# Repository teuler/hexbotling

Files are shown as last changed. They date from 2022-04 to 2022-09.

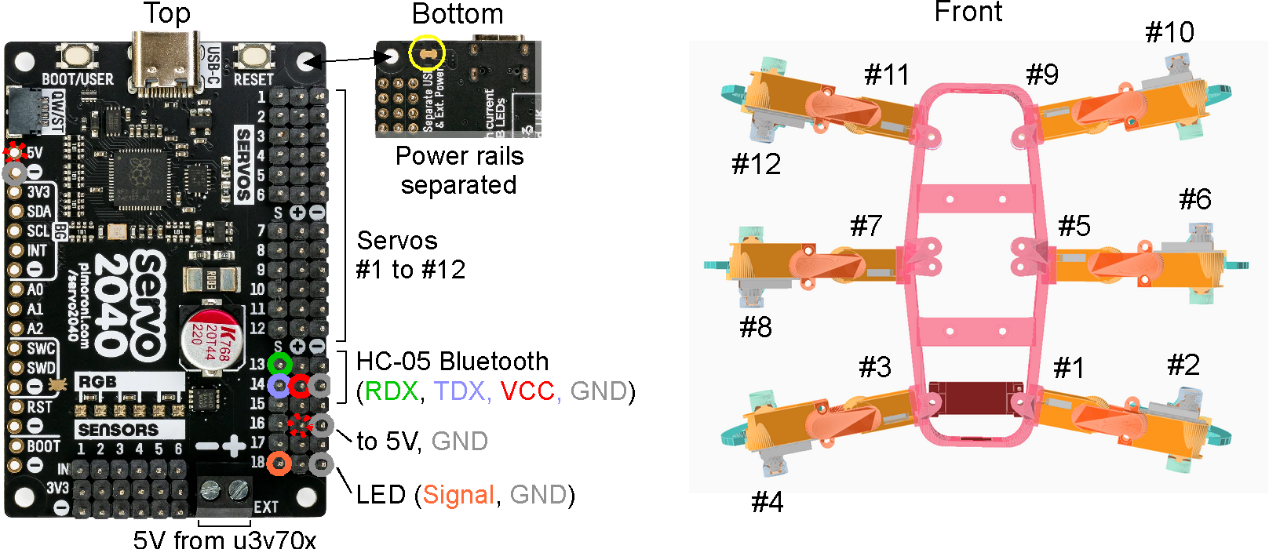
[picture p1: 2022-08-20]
pictures/setup_remote_version_1.png

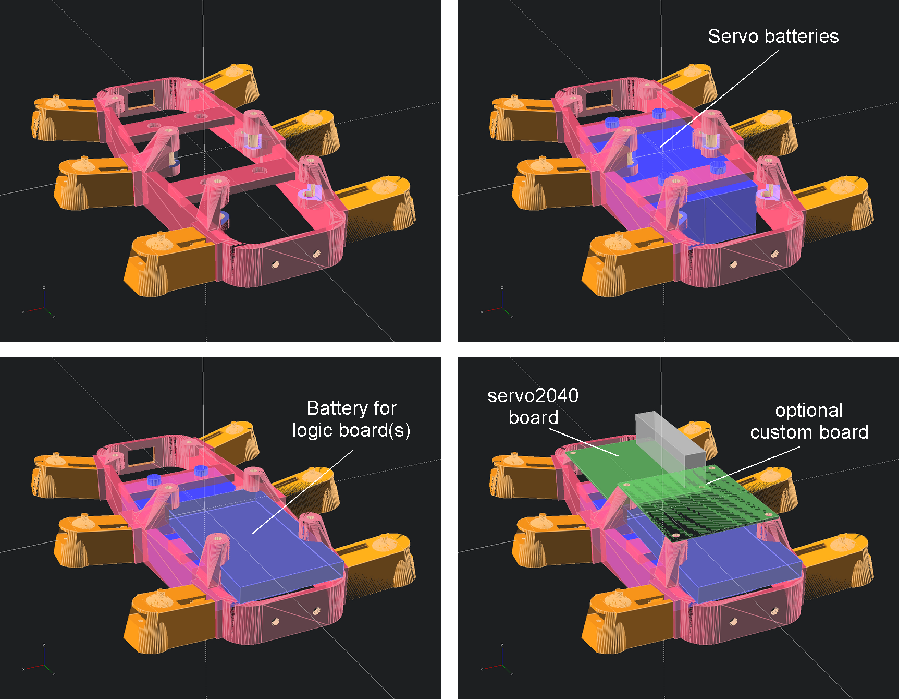
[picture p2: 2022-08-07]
pictures/body_design.png

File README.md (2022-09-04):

# Hexbotling

Hexbotling is a robotic project in progress. The goal is a relatively small and simple, 3D printed walking robot with 6 legs and 2 degrees-of-freedom (2DOF) each. Instead of documenting a finished project, I will show the development. 

Check out the [Wiki](https://github.com/teuler/hexbotling/wiki) for details.

The following videos are available:
* [How it began - Prototyping a leg](https://youtu.be/HZH1UBr0M4s)
* [Preview 1 - First steps](https://youtu.be/tBBJNqaDOq4)

### Release Notes

* 2022-09-03 - First pre-release of the code for the remote controlled test version.
* 2022-08-19 - `scad` code and `.stl` files updated (alternative foot). MicroPython code updated. Wiki pages describing the remote-controlled test version of the robot added.
* 2022-07-10 - `.scad` code updated; holder for servo voltage converter added.
* 2022-06-05 - `.stl` files for legs and body frame added; `.scad` code for these parts added as well.
* 2022-04-19 - Initial release

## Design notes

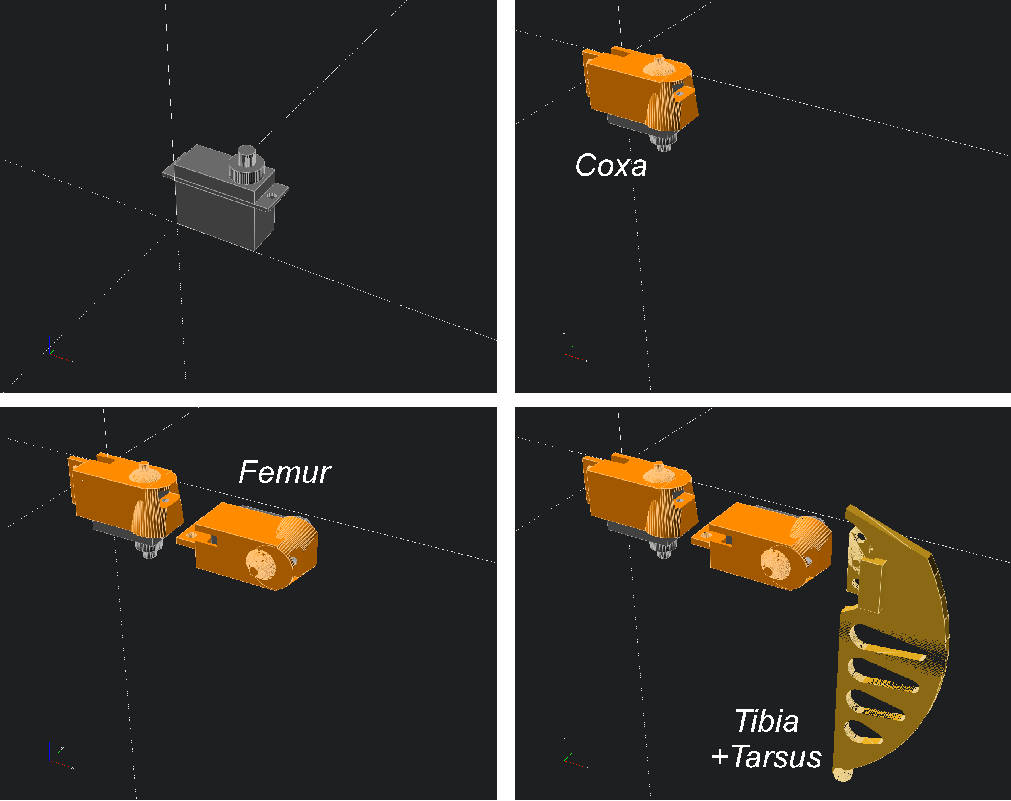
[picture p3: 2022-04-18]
pictures/leg_design.png

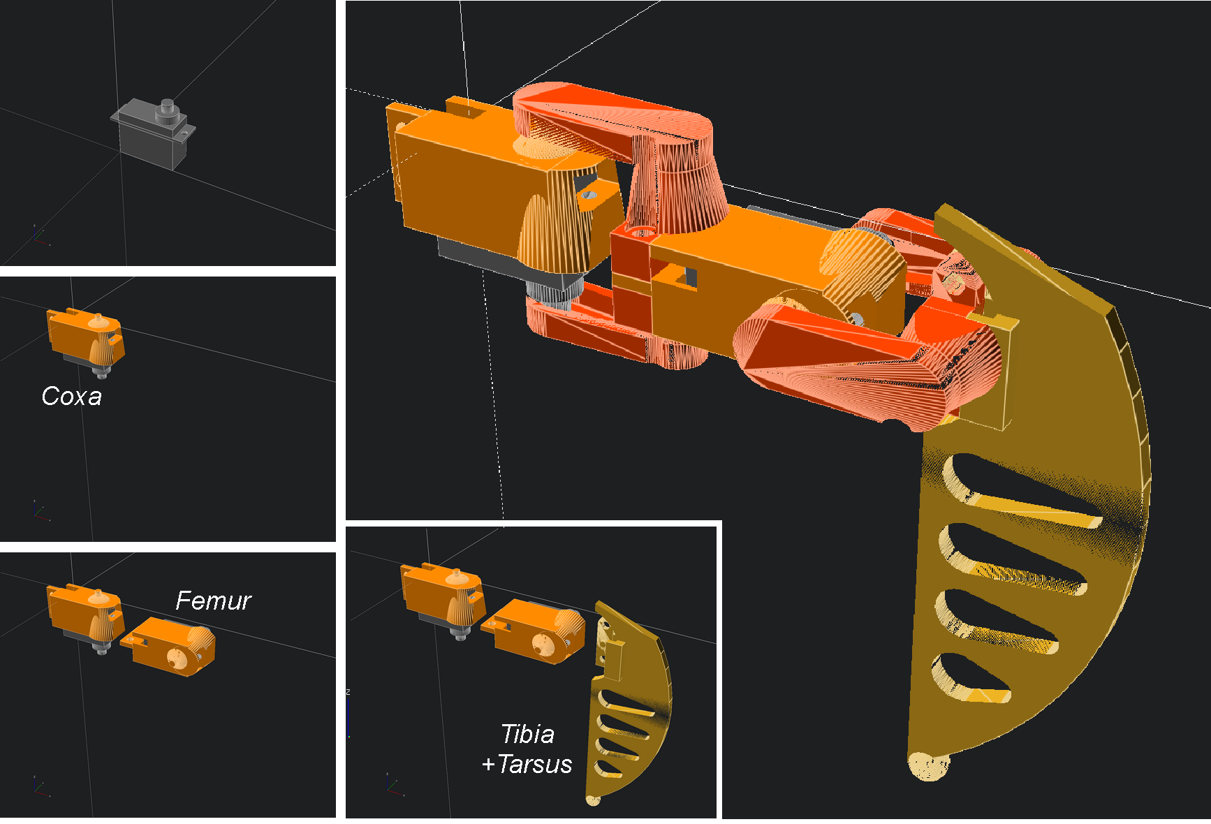
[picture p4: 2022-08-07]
pictures/leg_design_2.png

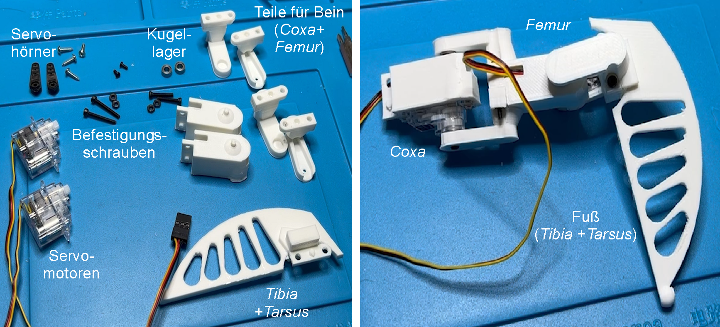
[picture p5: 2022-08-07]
pictures/leg_3_wLabels.png

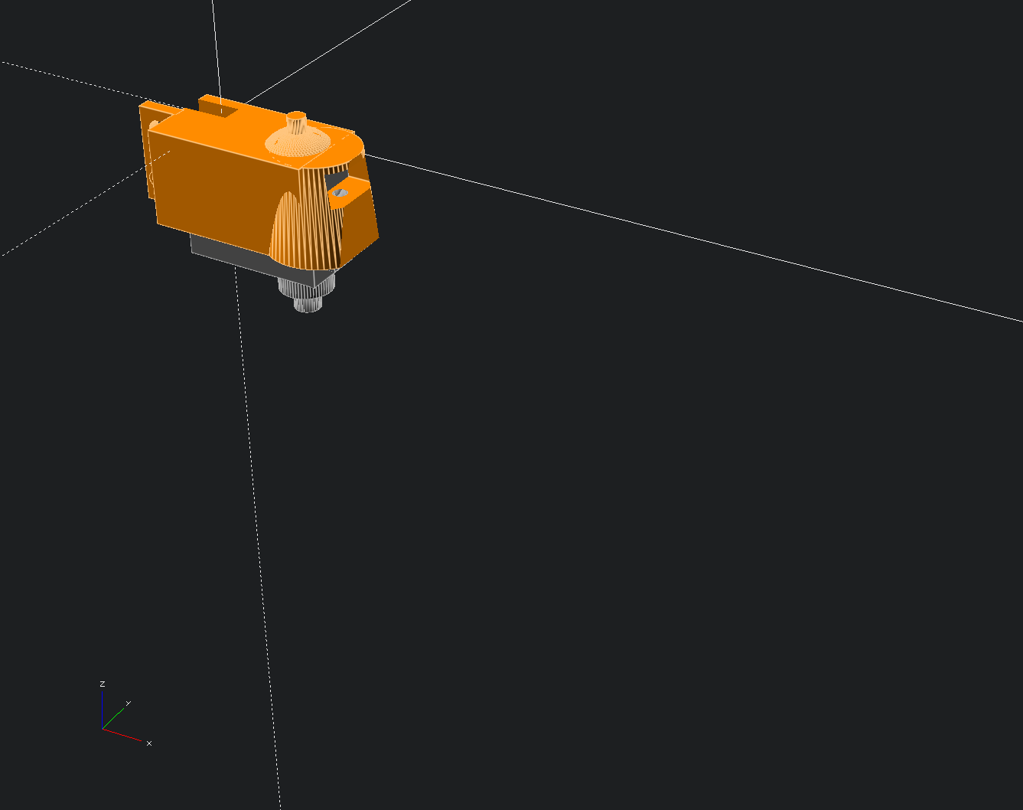
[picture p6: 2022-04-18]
pictures/scad_2.png

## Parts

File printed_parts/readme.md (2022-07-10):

## 3D printed parts

For [OpenSCAD](http://openscad.org/)-code files, see [subfolder](https://github.com/teuler/hexbotling/tree/main/printed_parts/openscad_files).

- `body_frame_v1.stl` - Frame of the robot, to which the legs are attached.
- `converter_holder_v1.stl` - Holder for servo voltage converter.
- `leg_coxa_femur_v1.stl` - Servo holder, which serves as base element for _coxa_ and _femur_. Note that the servo holder for the _coxa_ is integrated into the robot's frame
- `leg_link_bottom_v1.stl` - Bottom half of the clamp that connectes leg parts.
- `leg_link_top_v1.stl` - Top half of the clamp that connectes leg parts.
- `leg_tibia_tarsus_v1a.stl` - _Tibia_ and _tarsus_ in one piece (2DOF), so basically the "foot".
- `stand_v1.stl` - Stand to mount the robot on while calibrating/testing the leg movements.

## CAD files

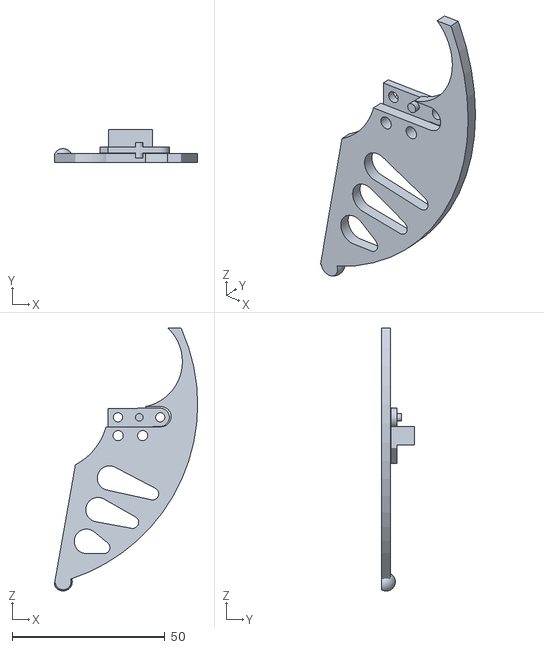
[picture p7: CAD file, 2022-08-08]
printed_parts/leg_tibia_tarsus_v2.stl
46.9 x 10.8 x 86.0

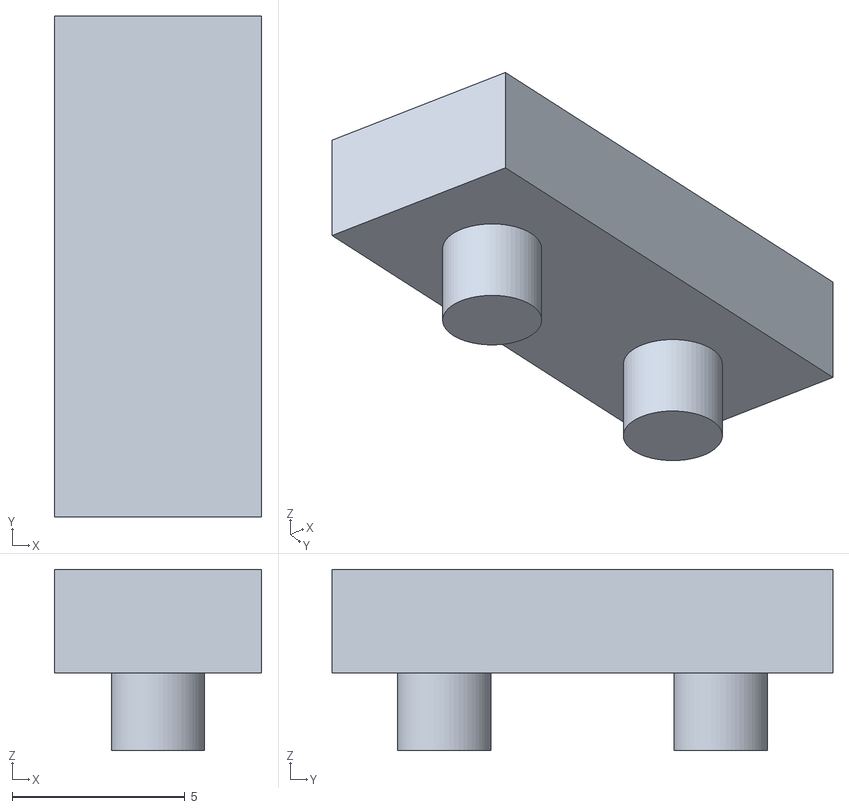
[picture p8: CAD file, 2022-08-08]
printed_parts/leg_tibia_tarsus_v2_adapter_v1.stl
6.00 x 14.5 x 5.25

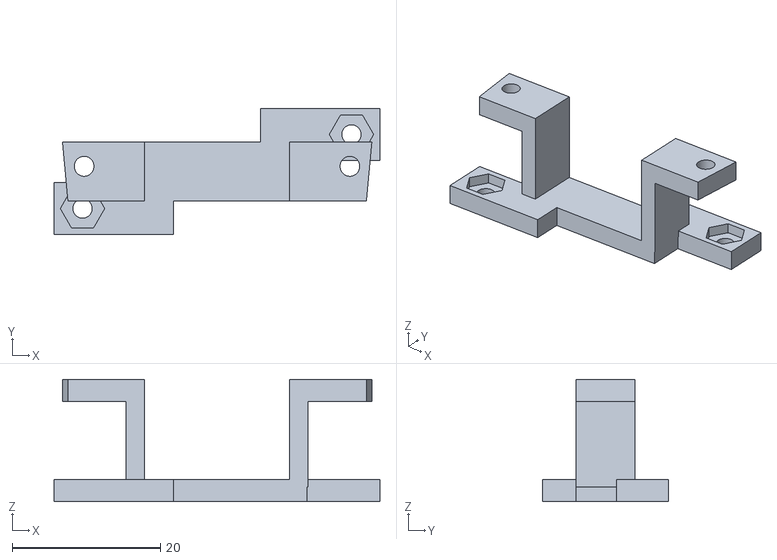
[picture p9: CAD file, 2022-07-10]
printed_parts/converter_holder_v1.stl
44.0 x 17.0 x 16.5

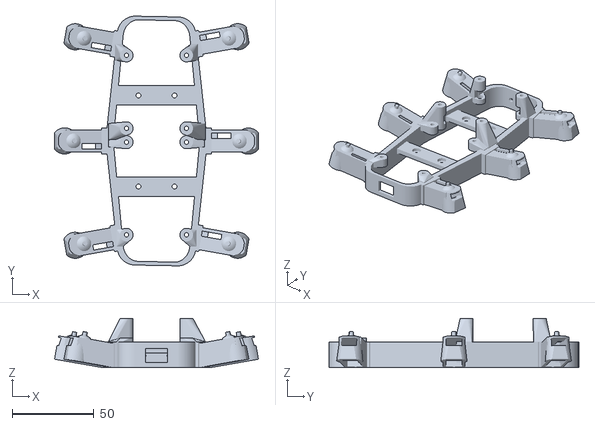
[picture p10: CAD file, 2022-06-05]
printed_parts/body_frame_v1.stl
124.6 x 152.5 x 30.0

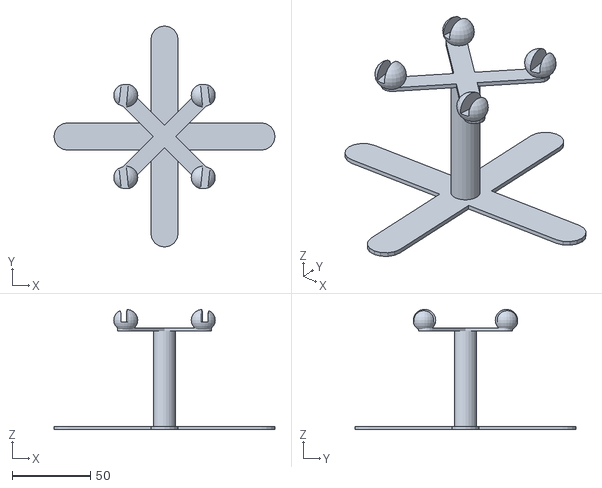
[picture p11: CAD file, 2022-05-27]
printed_parts/stand_v1.stl
141.2 x 141.2 x 76.9

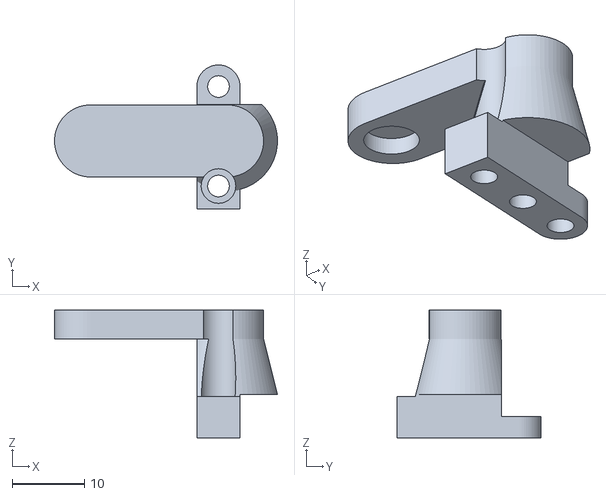
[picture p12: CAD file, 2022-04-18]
printed_parts/leg_link_top_v1.stl
30.9 x 20.0 x 17.8

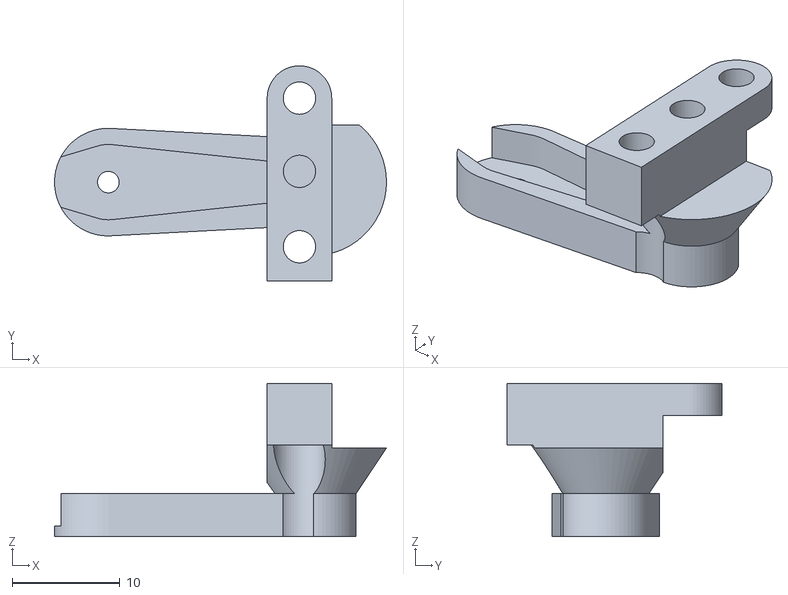
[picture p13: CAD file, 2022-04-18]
printed_parts/leg_link_bottom_v1.stl
30.8 x 20.0 x 14.2

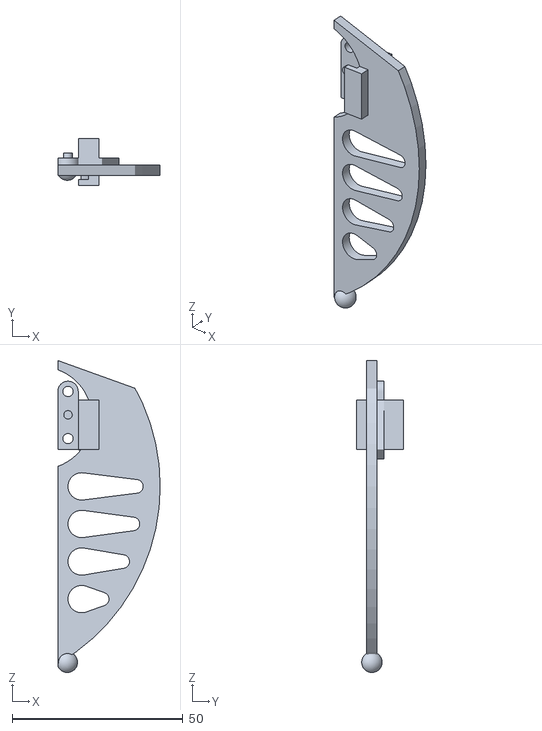
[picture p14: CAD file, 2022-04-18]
printed_parts/leg_tibia_tarsus_v1a.stl
30.0 x 13.8 x 91.4

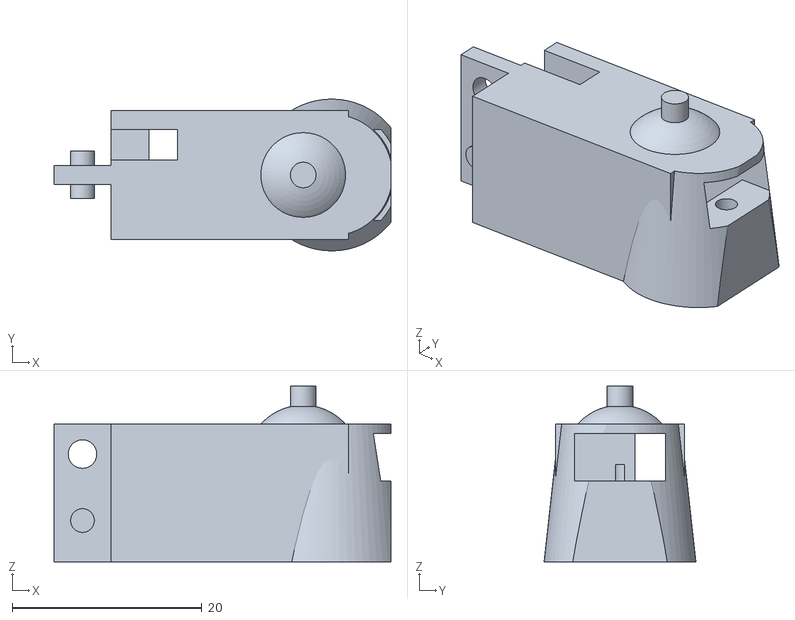
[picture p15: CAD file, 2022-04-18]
printed_parts/leg_coxa_femur_v1.stl
35.5 x 16.0 x 18.5

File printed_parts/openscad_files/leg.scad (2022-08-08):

// --------------------------------------------------------------------------------
// leg.scad (Hexabotling project)
// All modules that define a leg
// (not stand-alone; requires constants defined in the main program)
//
// The MIT License (MIT)
// Copyright (c) 2022 Thomas Euler
//
// --------------------------------------------------------------------------------
module _arm1(px, py, pz, select) {
  // Creates one side ("arm") of a clamp for the legs
  //
  module _front1() {
    translate([srv_axis_x +px -4, -srv_base_dy/2 +0.25, 5])  
    hull() {
      cylinder(h=4, r=5, $fn=_fn);
      translate([15+4, 0,0])  
        cylinder(h=4, r=5, $fn=_fn);
    }  
    translate([srv_axis_x +px +15, -srv_base_dy/2 +0.25, -3])  
      cylinder(h=8, r1=7, r2=5, $fn=_fn);
    translate([px +28, -14, -8.75])  
      cube([6,14.5,5.75]);  
  }
  module _back1() {
    translate([srv_axis_x +px -4, -srv_base_dy/2, 4])  
      cylinder(h=3, r=6.2/2, $fn=_fn);
    translate([srv_axis_x +px +0.75, -14, -21])  
      cube([10, 20, 26]);          
    translate([srv_axis_x +px +10, 0.5, -24])  
      cube([11, 10, 30]);     
    translate([34 +px, -15, -16.5 -0.25])  
      cube([6, 16.5, 13.5 +1 -0.5]);          
    _link_hole(px);  
  }
  if((select == 0) || (select == 1)) {
    difference() {
      union() {
        difference() {
          _front1();
          _back1();
        }
        if(arm_latches) 
          if((select == 0) || (select == 1))
            _arm_latch(px, pz);
      }      
      _link_pin_hole(px);
    }  
  }
}


module _arm2(px, py, pz, select) {
 // Creates the other side ("arm") of a clamp for the legs
 //
  module _front1() {
    translate([srv_axis_x +px -4, -srv_base_dy/2, -25])  
    hull() {
      cylinder(h=4, r=5, $fn=_fn);
      translate([15+4, 0,0])  
        cylinder(h=4, r=4, $fn=_fn);
    }  
    translate([srv_axis_x +px +15, -srv_base_dy/2, -21])  
      cylinder(h=4.5, r1=4, r2=7, $fn=_fn);
    translate([px +28, -14, -16.5])  
      cube([6,14.5,5.75]);          
  }
  module _back1() {
    hull() {
      translate([srv_axis_x +px-4, -srv_base_dy/2, -24])  
        cylinder(h=5, r=7/2, $fn=_fn);
      translate([srv_axis_x +px+15, -srv_base_dy/2, -24])  
        cylinder(h=5, r=3/2, $fn=_fn);
      translate([srv_axis_x +px-5 -6, -srv_base_dy/2, -24])  
        cylinder(h=5, r=3/2, $fn=_fn);
    }  
    translate([srv_axis_x +px -4, -srv_base_dy/2, -27])  
      cylinder(h=10, r=1.0, $fn=_fn);
    translate([srv_axis_x +px -4, -srv_base_dy/2, -27.75])  
      cylinder(h=3, r=6.5/2, $fn=_fn);

    translate([srv_axis_x +px +0.75, -14, -21])  
      cube([10, 20, 26]);          
    translate([srv_axis_x +px +10, 0.5, -24])  
      cube([11, 10, 30]);     
    translate([34 +px, -15, -16.5 -0.25])  
      cube([6, 16.5, 13.5 +1 -0.5]);          
    _link_hole(px);  
  }
  if((select == 0) || (select == 2)) {
    difference() {
      union() {
        difference() {
          _front1();
          _back1();
        }
        if(arm_latches) 
          if((select == 0) || (select == 2))
            _arm_latch(px, pz -5);
      }      
      _link_pin_hole(px);
    }
  }
}

// - - - - - - - - - - - - - - - - - - - - - - - - - - - - - - - - - - - - - - - - 
module _link_hole(px) {
  // Creates the hole for a leg link
  //
  translate([31+px, -4.8 +yoffs_link, -29]) {
    cylinder(h=42, r=r_hole2, $fn=_fn);        
    cylinder(h=10+5, r=r_hole3, $fn=_fn);        
  }
  translate([31+px, -4.8 +yoffs_link, 3-7]) 
    cylinder(h=10+5, r=r_hole3, $fn=_fn);        
}

module _link_pin_hole(px) {
  // Creates the pin for a leg link
  //
  translate([31+px, -9.8 -yoffs_link, -13.25]) 
    cylinder(h=7, r=r_hole2, $fn=_fn);        
}

module _arm_latch(px,pz,dz=3) {
  // Creates the latch that allows combining to leg elements via a clamp
  //
  color("Orange", _alpha1)  
  difference() {
    hull() {
      translate([px +28+3, -4, -8.75 +pz])  
        cylinder(h=dz, r=3, $fn=_fn);      
      translate([px +28+3, 3, -8.75 +pz])    
        cylinder(h=dz, r=3, $fn=_fn);      
    }   
    union() {
      translate([px +28+3, 3, -8.75 +pz+-3])    
        cylinder(h=10, r=1.5, $fn=_fn);      
    }
  }
}

// --------------------------------------------------------------------------------
module Coxa(pxyz=[0,0,0], wServo=false, wSlit=false, noConnect=false) { 
  // Creates the coxa 
  //
  module _body() {
    w = 2;
    translate([-w*2, -w, -w])
      cube([srv_base_dx +w*2, srv_base_dy +w*2, srv_base_dz+ w], center=false);  
    _r = 8;  
    translate([srv_axis_x+2, srv_base_dy/2, -w])  
    cylinder(h=srv_base_dz +2, r1=_r-1.6, r2=_r, $fn=_fn);
    translate([srv_axis_x+srv_axis_x_corr, srv_base_dy/2, -w-4])  
    cylinder(h=3, r=1.35, $fn=_fn);
    translate([srv_axis_x+srv_axis_x_corr, srv_base_dy/2, +2])  
    sphere(r=_r-2, $fn=_fn);
    if(!noConnect)
      translate([-10, srv_base_dy/2 -1, -2])
      cube([6.5, 2, srv_base_dz +w], center=false);  
    if(wSlit) {  
      translate([-10 -1, srv_base_dy/2 -1 -0.5, -2 -1])
      cube([6.5 +1, 2 +1, srv_base_dz +w +2.5], center=false);  
    }
    /*
    translate([srv_axis_x, srv_base_dy/2, -w-4-5])  
      cylinder(h=40, r=1.35, $fn=_fn);
    */  
  }
  module _link_pin() {
    rotate([90,0,0]) 
    translate([-7, srv_base_dz/2 -4.1 -yoffs_link, -7.25]) {
      cylinder(h=5, r=r_hole2-0.25, $fn=_fn);        
      if(wSlit) {
        _dy = (r_hole2-0.25)*2.5;
        translate([-3, -_dy/2, -0.5])
        cube([10, _dy, 6]);
      }  
    }    
  }
  module _link_hole() {
    // Link hole
    rotate([90,0,0]) 
    translate([-7, srv_base_dz/2 +0.9 +yoffs_link, -20]) {
      cylinder(h=30, r=r_hole2, $fn=_fn);          
      if(wSlit) {
        translate([0,0,-4.5])
        cylinder(h=10, r=r_hole2+2, $fn=_fn);        
        translate([0,0,25.2])
        cylinder(h=10, r=r_hole2+2, $fn=_fn);        
      }
    }  
  }  
  
  rotate([180,0,0])
  translate(pxyz) {
    color("DarkOrange",_alpha1)
    difference() {
      union() {
        _body();
        if(wSlit)
          _link_hole();
      }  
      union() {
        Servo([0,0,0.5], wHoles=!wSlit);
        translate([25.5,-4,-3])
          cube([10, 16, srv_base_dz+4]);
        translate([-1, 0, -1])
          cube([28, srv_base_dy, 5]);        
        if(!wSlit) {
          _l = !noConnect? 8: 16;  
          translate([-5, 0, -4])
            cube([_l, srv_base_dy/3, srv_base_dz +2]);      
        }  
        if(!wSlit)
          _link_hole();
      }
    }
    color("DarkOrange", _alpha1)
    _link_pin();    
    if(wServo)
      color("DimGray", _alpha2)
      Servo();
  }
}

// --------------------------------------------------------------------------------
module Femur(pxyz=[0,0,0], wServo=false, select=0) {
  // Creates the femur
  //
  px = pxyz[0] +4;
  py = pxyz[1];
  pz = pxyz[2];
  if((select == 0) || (select == 3)) {
    rotate([90,0,0]) 
      Coxa([px +38, py+5, pz-12], wServo);
  }
  color("OrangeRed", _alpha1)  
  union() {
    _arm1(px, py, pz, select);
    _arm2(px, py, pz, select);
  }  
}

// --------------------------------------------------------------------------------
module Tibia1(pxyz=[0,0,0], select=0) {
  // Creates the tibia
  //
  px = pxyz[0] +8;
  py = pxyz[1];
  pz = pxyz[2];
  _rot = [0, 0, 0];
  _tra = [0, 0, 0];
  
  rotate([90,0,0])
  translate([30 +px, -5+py, 12+pz]) {
    // Arms
    color("OrangeRed", _alpha1)      
    rotate(_rot) 
    translate(_tra)
    union() {
      _arm1(px, py, pz, select);
      _arm2(px, py, pz, select);
    }
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

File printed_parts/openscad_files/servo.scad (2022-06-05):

// --------------------------------------------------------------------------------
// servo.scad (Hexabotling project)
// Modules that define a micro servo
// (stand-alone)
//
// The MIT License (MIT)
// Copyright (c) 2022 Thomas Euler
//
// --------------------------------------------------------------------------------
srv_dspace       = 0.5;
srv_fn           = 60;

// Servo definitions
srv_base_dx      = 20 +srv_dspace*2;
srv_base_dy      = 8.6 +srv_dspace*2;
srv_base_dz      = 12 +srv_dspace;
srv_bar_dx       = 28;
srv_bar_dz       = 1;
srv_top_dz       = 17 -srv_bar_dz -srv_base_dz;
srv_top2_dz      = 20.2 -17;
srv_top3_dz      = 23.5 -20.2;
srv_hole_dist_dx = 17.5 +6;
srv_hole1_x      = (srv_bar_dx -srv_hole_dist_dx)/2;
srv_hole2_x      = srv_hole1_x +srv_base_dx;
srv_axis_x       = srv_hole2_x -6;
srv_axis_x_corr  = -1;

module Servo(pxyz=[0,0,0], axyz=[0,0,0], wHoles=false) {
  // Creates a servo 
  //
  module _Holes() {
    union() {
      translate([-srv_hole1_x+0.25+0.35, srv_base_dy/2, srv_base_dz-4]) 
        cylinder(h=srv_base_dz, r=r_hole4, center=true, $fn=srv_fn);
      translate([srv_hole2_x-0.5-0.35, srv_base_dy/2, srv_base_dz-4]) 
        cylinder(h=srv_base_dz, r=r_hole4, center=true, $fn=srv_fn);
    }
  }
  color("DimGray", _alpha2)
  translate(pxyz) 
  rotate(axyz)
  difference() {
    union() {
      cube([srv_base_dx, srv_base_dy, srv_base_dz], center=false);
      translate([-(srv_bar_dx -srv_base_dx)/2,0, srv_base_dz]) 
        cube([srv_bar_dx, srv_base_dy, srv_bar_dz], center=false);
      translate([0,0, srv_base_dz +srv_bar_dz]) 
        cube([srv_base_dx, srv_base_dy, srv_top_dz], center=false);
      z = srv_base_dz +srv_bar_dz +srv_top_dz;
      translate([srv_axis_x+srv_axis_x_corr, srv_base_dy/2, z]) {
        cylinder(h=srv_top2_dz, r=8/2, center=false, $fn=srv_fn);
        cylinder(h=srv_top3_dz +srv_top2_dz, r=4/2, center=false, $fn=srv_fn);
      }
    }
    _Holes();
  }
  if(wHoles)
    _Holes();
}

// --------------------------------------------------------------------------------

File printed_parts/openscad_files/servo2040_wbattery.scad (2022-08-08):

// --------------------------------------------------------------------------------
// servo2040_wbattery.scad (Hexabotling project)
// Modules that define a servo2040 board and the servo battery pack
// (not stand-alone; requires constants defined in the main program)
//
// The MIT License (MIT)
// Copyright (c) 2022 Thomas Euler
//
// --------------------------------------------------------------------------------
module ServoBattery(n=2) {
  // Creates a servo battery pack
  // (BH-18650-PC_DS Battery holder)
  //
  color("Blue", _alpha2) {
    _zbat = -13+1 -3; 
    dx = [11, -11];
    _h = 8;
    for(i=[0:n-1]) {
      translate([n>1?dx[i]:0, 0, _zbat]) {
        cube([22.9, 77.7, 21.3], center=true); 
        
        translate([0, 55.6/2, 5])
        cylinder(h=_h, r=3/2, $fn=_fn);
        translate([0, 55.6/2, 12])
        cylinder(h=_h, r=6/2, $fn=_fn);

        translate([0, -55.6/2, 5])
        cylinder(h=_h, r=3/2, $fn=_fn);
        translate([0, -55.6/2, 12])
        cylinder(h=_h, r=6/2, $fn=_fn);
        
      }
    }
  }
}    

// --------------------------------------------------------------------------------
function PCB_servo2040_metrics() 
  = [srv2040_dx, srv2040_dy, 
     [[ srv2040_dx/2 -2.7,  srv2040_dy/2 -2.7], 
      [-srv2040_dx/2 +2.7,  srv2040_dy/2 -2.7],
      [ srv2040_dx/2 -2.7, -srv2040_dy/2 +2.7], 
      [-srv2040_dx/2 +2.7, -srv2040_dy/2 +2.7]
     ]];

// - - - - - - - - - - - - - - - - - - - - - - - - - - - - - - - - - - - - - - - -      
module PCB_servo2040(holes_only=false, screw_only=false) {
  // Creates a Pimoroni servo2040 board
  //
  _temp = PCB_servo2040_metrics();
  _dx = _temp[0];
  _dy = _temp[1];
  _xy = _temp[2];
  
  module _pbc() {
    color("ForestGreen", _alpha2)
    cube([_dx, _dy, 1], center=true);
    color("gray", _alpha2)
    translate([0, -_dy/2 +9.5/2, -15/2])
    cube([_dx-2*5, 9.5, 15], center=true);
  }  
  module _holes(_h) {
    for(xy=_xy) {    
      translate([xy[0], xy[1], -2])
      cylinder(h=_h, r=2.7/2, $fn=_fn);
      if(!screw_only) 
        translate([xy[0], xy[1], 15])
        cylinder(h=15, r=2.3, $fn=_fn);
    }  
  }

  rotate([180,0,90]) 
  translate([srv2040_offx, 0, srv2040_offz]) 
  union() {
    if(holes_only) {
      translate([0,0,-10])
      _holes(_h=30);
    }
    else {
      difference() {
        _pbc();
        _holes(_h=10);
      }  
    } 
   } 
}
 
// --------------------------------------------------------------------------------

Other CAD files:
printed_parts/openscad_files/main_v6.scad
printed_parts/openscad_files/main_v4.scad
printed_parts/openscad_files/main_v5.scad
printed_parts/openscad_files/stand.scad

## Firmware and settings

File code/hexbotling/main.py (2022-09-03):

# ----------------------------------------------------------------------------
# main.py
#
# Main program
#
# The MIT License (MIT)
# Copyright (c) 2022 Thomas Euler
# 2022-03-21, v1.0
# ----------------------------------------------------------------------------
import sys
import time
import hxbl_global as glb
import hxbl_config as cfg
import hxbl_comm as com
from hxbl_server import Server
from robotling_lib.misc.helpers import timed_function
from robotling_lib.misc.messenger import MessengerUART
import hxbl_server

# ----------------------------------------------------------------------------
#@timed_function
def handleCmd(msgData):
  """ Handles command in `msgData`, returns ERR_OK or error code
  """
  res = Comm.check(msgData)
  if res is not glb.ERR_OK:
    # Invalid message
    return res, com.MSG_NONE

  # Extract elements
  RSrv.set_msg_LED(True)
  errC = glb.ERR_OK
  msgID = msgData[1]
  params = msgData[2:]
  nParams = len(params)

  # Handle command ...
  if msgID == com.MSG_STOP:
    # Stop robot and wait until in neutral position
    RSrv.stop(wait_for_neutral=True)

  elif msgID == com.MSG_GAIT:
    # Change gait
    RSrv.stop(wait_for_neutral=True)
    RSrv.set_gait_parameters(type=params[0])

  elif msgID == com.MSG_MOVE:
    # Move robot depending on parameters ...
    dir = min(max(params[0], -100), 100) /100
    vel = min(max(params[1]*2, 1), 250) / 100
    rev = params[2] > 0
    lft = params[3]
    RSrv.set_gait_parameters(velocity=vel, lift_deg=lft)
    hxbl_server.g_we._tLastMsg = time.ticks_ms()
    if abs(dir) < 0.1:
      # ... forward
      RSrv.move_forward(reverse=rev)
    else:
      # ... turn
      RSrv.turn(dir)

  elif msgID == com.MSG_POWER_DOWN:
    # Power down
    pass

  elif msgID == com.MSG_PING:
    # Client sent a ping, respond ...
    Comm.send([com.MSG_PING])

  else:
    # Command not recognized
    errC = glb.ERR_UNKNOWN_MSG
    msgID = com.MSG_NONE

  if errC is glb.ERR_OK and msgID is not com.MSG_PING:
    sendStatus(msgID)
  RSrv.set_msg_LED(False)
  return errC, msgID

# - - - - - - - - - - - - - - - - - - - - - - - - - - - - - - - - - - - - - -
#@timed_function
def sendStatus(msgID):
  """ Confirm receipt/execution of command. Includes:
      - message ID (`msgID`)
      - the servo load (in [A]*10)
      - the servo battery voltage (in [V]*10)
  """
  Comm.send(
      [com.MSG_STA, msgID,
      int(RSrv.servo_load_A *10), int(RSrv.servo_battery_V *10)]
    )

# ----------------------------------------------------------------------------
if __name__ == "__main__":

  # Create server instance
  RSrv = Server(core=cfg.HW_CORE, verbose=True)

  # Create a communicator instance and wait for connection to client
  Comm = com.Communicator(MessengerUART(
      chan=cfg.UART_CH, fToLog=glb.toLog,
      tx=cfg.UART_PIN_TX, rx=cfg.UART_PIN_RX, baud=cfg.UART_BAUD
    ))
  RSrv.set_pulse_LED_hue(cfg.HUE_WAITING)
  glb.toLog("Wait for ping from server ...")
  if not Comm.wait_for_client(f_wait_ms=RSrv.sleep_ms):
    glb.toLog("No client connection", errC=glb.ERR_CANNOT_CONNECT)
    RSrv.deinit()
    sys.exit()
  else:
    RSrv.set_pulse_LED_hue(cfg.HUE_NORMAL_BT)
  glb.toLog("Ready.", head=False)

  try:
    is_running = True
    n_rounds = 0
    msgID = com.MSG_NONE

    # Main loop
    glb.toLog("Entering loop ...", head=False)
    try:
      while not RSrv.state == glb.STA_OFF and is_running:
        # Get sensor input and/or commands from client
        # ...

        # Check if message is available
        if Comm.available > 0:
          data = Comm.receive()
          if data is not None and len(data) > 0:
            # If message data ok, handle the message ...
            errC, msgID = handleCmd(data)
            if errC is not glb.ERR_OK:
              glb.toLog("Command not handled", errC=errC)

        # Sleep for a while and, if running only on one core, make sure that
        # the server's hardware is updated
        RSrv.sleep_ms(25)

        # Check if user button is pressed; when debugging, exit also if a
        # maximum number of rounds have been done, as a precaution
        is_running = (
            not RSrv.exit_requested
            and not msgID == com.MSG_POWER_DOWN
          )
        if cfg.DEBUG:
          is_running = is_running and n_rounds < 25_000
        n_rounds += 1

    except KeyboardInterrupt:
      is_running = False
      pass

  finally:
    # Power down and clean up
    glb.toLog("Loop stopped.", head=False)
    RSrv.deinit()

# ----------------------------------------------------------------------------

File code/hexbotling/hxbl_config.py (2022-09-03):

# ----------------------------------------------------------------------------
# hxbl_config.py
#
# Configuration
#
# The MIT License (MIT)
# Copyright (c) 2022 Thomas Euler
# 2022-05-04, v1.0
# 2022-08-07, v1.1 - Improved calculation of the servo calibration values
# ----------------------------------------------------------------------------
import array
from micropython import const
from servo import servo2040 as srv

# pylint: disable=bad-whitespace
# Firmware info
HXBL_VERSION       = 1.1
HXBL_INFO          = "Hexbotling"
DEBUG              = const(1)
CALIBRATE          = []

# Control how hardware is kept updated
HW_CORE            = const(0)   # 1=hardware update runs on second core
APPROX_SPIN_MS     = const(5)   # core==0, approx. duration of hardware update
MIN_UPDATE_MS      = const(20)  # core==0, minimal time between hardware updates
PULSE_STEPS        = const(25)  # Number of steps for Pixel/RGB pulsing

# Global parameters
MAX_CURR_A         = 1.0         # maximum for normalizing sensed current
DT_CURR_UPDATE     = const(50)
MAX_VOLT_V         = 5.5         # maximum for normalizing voltage
BATT_SERVO_THRES_V = 4.6
DT_VOLT_UPDATE     = const(1000)

# LED-related
LEDS_BRIGHTNESS    = 0.4         # maximum LED brighness (0..1)
LEDS_FREQ          = const(60)   # Hz (frequency of LED driver)
ID_LED_CURR        = const(0)    # ID of LED for current load indicator
ID_LED_VOLT        = const(1)    # ID of LED for servo voltage indicator
ID_LED_PULSE       = const(5)    # ID of pulsing LED
HUE_PREPARING      = 0.2
HUE_NORMAL_BT      = 0.6
HUE_WAITING        = 0.0

# Pins for message UART
UART_CH            = const(0)
UART_PIN_TX        = const(12)   # RDX  ->  SERVO13 (GP12, UART0 TX)
UART_PIN_RX        = const(13)   # TDX  ->  SERVO14 (GP13, UART0 RX)
UART_BAUD          = const(115_200)

# Other pins
MSG_LED_PIN        = const(17)

# ----------------------------------------------------------------------------
# Leg- and servo-related definitions and calibration data
#
# Leg order:
# ---------
# front   0  __  1
#          \|  |/
# center 2--|  |--3
#          /|__|\
# back    4      5
#
LEG_FL            = const(0)
LEG_FR            = const(1)
LEG_CL            = const(2)
LEG_CR            = const(3)
LEG_BL            = const(4)
LEG_BR            = const(5)

# Servo order (IDs):
# -----------
#    --1--0  __  -2--3-
#          \|  |/
#   --5--4--|  |---6--7-
#          /|__|\
#    --9--8      10-11-
#
SRV_COUNT         = const(12)
SRV_ID            = bytearray([0,1, 2,3, 4,5, 6,7, 8,9, 10,11])

# Servo ranges (for all legs)
SRV_RANGE_DEG     = [(-45, 45), (-30, 90)]
SRV_RESTING_DEG   = [0,0] *6
SRV_US_PER_DEG    = 450 /45  # us per degree
SRV_CX_OFFS1      = int(SRV_RANGE_DEG[0][0] *SRV_US_PER_DEG)
SRV_CX_OFFS2      = int(SRV_RANGE_DEG[0][1] *SRV_US_PER_DEG)
SRV_FM_OFFS1      = int(SRV_RANGE_DEG[1][0] *SRV_US_PER_DEG)
SRV_FM_OFFS2      = int(SRV_RANGE_DEG[1][1] *SRV_US_PER_DEG)

SRV_RANGE_US      = [
    (1395+SRV_CX_OFFS1, 1395+SRV_CX_OFFS2),  # 0
    (1400+SRV_FM_OFFS1, 1400+SRV_FM_OFFS2),  # 1
    (1500+SRV_CX_OFFS1, 1500+SRV_CX_OFFS2),  # 2
    (1460+SRV_FM_OFFS1, 1460+SRV_FM_OFFS2),  # 3
    (1585+SRV_CX_OFFS1, 1585+SRV_CX_OFFS2),  # 4
    (1260+SRV_FM_OFFS1, 1260+SRV_FM_OFFS2),  # 5
    (1575+SRV_CX_OFFS1, 1575+SRV_CX_OFFS2),  # 6
    (1400+SRV_FM_OFFS1, 1400+SRV_FM_OFFS2),  # 7
    (1640+SRV_CX_OFFS1, 1640+SRV_CX_OFFS2),  # 8
    (1295+SRV_FM_OFFS1, 1295+SRV_FM_OFFS2),  # 9
    (1755+SRV_CX_OFFS1, 1755+SRV_CX_OFFS2),  # 10
    (1600+SRV_FM_OFFS1, 1600+SRV_FM_OFFS2)   # 11
  ]

SRV_PIN           = bytearray([
    srv.SERVO_11, srv.SERVO_12, srv.SERVO_9, srv.SERVO_10,
    srv.SERVO_7,  srv.SERVO_8,  srv.SERVO_5, srv.SERVO_6,
    srv.SERVO_3,  srv.SERVO_4,  srv.SERVO_1, srv.SERVO_2
  ])

SRV_COX           = bytearray([0,2,4,6,8,10])
SRV_COX_DIR       = array.array("h", [ 1,-1, 1,-1, 1,-1])
SRV_FEM           = bytearray([1,3,5,7,9,11])

SRV_MIN_US        = const(700)
SRV_MAX_US        = const(2300)
# pylint: enable=bad-whitespace

# ----------------------------------------------------------------------------

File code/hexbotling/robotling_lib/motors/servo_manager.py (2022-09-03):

# ----------------------------------------------------------------------------
# servo_manager.py
# Class to manage and control a number of servos
#
# The MIT License (MIT)
# Copyright (c) 2020-2022 Thomas Euler
# 2020-01-03, v1
# 2020-08-02, v1.1 ulab
# 2020-10-31, v1.2, use `languageID` instead of `ID`
# 2021-02-14, v1.3, small improvements towards more performance
# 2021-02-28, v1.4, compatibility w/ rp2, no `ulab` for space reasons
# 2022-01-04, v1.5, Nano RP2040 Connect added, simplified (only linear)
# 2022-05-05, v1.6, Calibration code added
# 2022-05-08, v1.7, TRJ_LINEAR=Normal, TRJ_SINE=slow start and end move
# 2022-06-11, v1.8, Allow setting last position after power-off
# 2022-06-26, v1.8, Added option not to use `ulab`
# 2022-08-10, v1.8, Added `trajectory` as property
# 2022-08-10, v1.9, Added more trajectory types
# ----------------------------------------------------------------------------
import gc
import time
import array
from machine import Timer
from robotling_lib.misc.helpers import timed_function
from robotling_lib.platform.platform import platform as pf
import robotling_lib.misc.ansi_color as ansi
try:
  from ulab import numpy as np
  ULAB = True
except ImportError:
  import math as np
  ULAB = False

# pylint: disable=bad-whitespace
__version__        = "0.1.9.0"
RATE_MS            = const(15)  # 5=hangs, 15...20=ok, 25=not continues
HARDWARE_TIMER     = const(0)
# pylint: enable=bad-whitespace

# ----------------------------------------------------------------------------
class ServoManager(object):
  """Class to manage and control a number of servos"""
  # pylint: disable=bad-whitespace
  TYPE_NONE       = const(0)
  TYPE_HORIZONTAL = const(1)
  TYPE_VERTICAL   = const(2)
  TYPE_SENSOR     = const(3)

  TRJ_LINEAR      = const(1)
  TRJ_SINE        = const(2)
  TRJ_RAMP_UP     = const(3)
  TRJ_RAMP_DOWN   = const(4)
  # pylint: enable=bad-whitespace

  def __init__(self, n, verbose=False):
    """ Initialises the management structures
    """
    self._isVerbose = verbose
    self._nChan = max(1, n)
    self._Servos = [None]*n                               # Servo objects
    self._servo_type = bytearray([TYPE_NONE]*n)           # Servo type
    self._servo_number = bytearray([255]*n)               # Servo number
    self._servoPos = array.array("f", [0]*n)              # Servo pos [us]
    self._SIDList = bytearray([255]*n)                    # Servos to move next
    self._targetPosList = array.array("H", [0]*n)         # Target pos [us]
    self._currPosList = array.array("f", [-1]*n)          # Current pos [us]
    self._stepSizeList = array.array("f", [0]*n)          # .. step sizes [us]
    self._nToMove = 0                                     # # of servos to move
    self._dt_ms = 0                                       # Time period [ms]
    self._nSteps = 0                                      # countdown of steps to move
    self._trajNormList = array.array("f", [0]*n)          # Sensor norm factor (TRJ_SINE)
    self._iStep = 0                                       # Current step
    self._nStTotal = 0                                    # total # of steps
    self._mm18 = None
    self._isMoving = False
    self._isFirstMove = True
    self._traject = TRJ_LINEAR
    self._Timer = Timer() if pf.isRP2 else Timer(HARDWARE_TIMER)

  def add_servo(self, i, servoObj, pos=0):
    """ Add at the entry `i` of the servo list the servo object, which has to
        define the following functions:
        - `write_us(t_us)`
        - `angle_in_us(value=None)`
        - `off()`
        - `deinit()`
    """
    if i in range(self._nChan):
      self._Servos[i] = servoObj
      self._servoPos[i] = servoObj.angle_in_us()
      self._servo_number[i] = i
      if self._isVerbose:
        print("Add servo #{0:-2.0f}, at {1} us"
              .format(i, int(self._servoPos[i])))
      try:
        self._mm18 = servoObj._mm18
      except AttributeError:
        pass

  def set_servo_type(self, i, type):
    """ Change servo type (see `TYPE_xxx`)
    """
    if i in range(self._nChan) and self._Servos[i] is not None:
      self._servo_type[i] = type

  def define_servo_pos(self, _pos):
    """ Define servo position (from angle) without moving the servo,
        e.g. to define the last starting position at power-off
    """
    if len(_pos) == self._nChan:
      for i in range(self._nChan):
        if self._Servos[i] is not None:
          t = self._Servos[i].angle_in_us(_pos[i])
          self._servoPos[i] = t
          self._currPosList[i] = t

  def turn_all_off(self, deinit=False):
    """ Turn all servos off
    """
    for servo in self._Servos:
      if not servo is None:
        servo.off()
        if deinit:
          servo.deinit()

  def deinit(self):
    """ Clean up
    """
    self._Timer.deinit()
    self.turn_all_off(deinit=True)

  # - - - - - - - - - - - - - - - - - - - - - - - - - - - - - - - - - - - - -
  @timed_function
  def move_timed(self, servos, pos, dt_ms=0):
    self.move(servos, pos, dt_ms, lin_vel)

  #@micropython.native
  def move(self, servos, pos, dt_ms=0):
    """ Move the servos in the list to the positions given in `pos`.
        If `dt_ms` > 0, then it will be attempted that all servos reach the
        position at the same time (that is after `dt_ms` ms)
    """
    # Stop ongoing move
    self._isMoving = False
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

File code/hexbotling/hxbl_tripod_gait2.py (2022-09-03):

# ----------------------------------------------------------------------------
# hxbl_tripod_gait2.py
#
# Tripod gait class (more phases)
#
# The MIT License (MIT)
# Copyright (c) 2022 Thomas Euler
# 2022-08-19, v1.2 - More phases
# ----------------------------------------------------------------------------
import array
import time
import hxbl_config as cfg
import hxbl_global as glb
from hxbl_gait_base import GaitBase
from robotling_lib.motors.servo_manager import ServoManager as sma

# pylint: disable=bad-whitespace
__version__  = "0.1.2.0"
# pylint: enable=bad-whitespace

# ----------------------------------------------------------------------------
class TripodGait(GaitBase):
  """Tripod gait class"""

  def __init__(self):
    # Initializing ...
    super().__init__()
    self._gaitType = "Tripod2"
    self._subtypes = [0,1]
    self.reset()
    glb.toLog("Gait set to `tripod2`")

  def reset(self):
    """ Resets current gait
    """
    super().reset()
    self._aCoxaSwing_deg = 23
    self._aCoxaCenter_deg = 0
    self._aLgLift_deg = 30
    self._aLgPreLift_deg = 30
    self._aLgDown_deg = 5
    self._nPhase = [4, 6][self._subtype]
    self._tPhase_ms = 1000
    self._aMaxCoxa_deg = 40
    self._phaseRatio = 0.30
    self._legSets = [
        bytearray([cfg.LEG_FL, cfg.LEG_CR, cfg.LEG_BL]),
        bytearray([cfg.LEG_FR, cfg.LEG_CL, cfg.LEG_BR])
      ]

  def _set_subtype(self, val):
    """ Set gait subtype
    """
    val = val if val in self._subtypes else 0
    if self._subtype != val:
      self._subtype = val
      self.reset()

  def get_next_servo_pos(self, stop=False, turn_dir=0, rev=False):
    """ Returns a tuple consisting of the duration of the move (in ms) and an
        array of angles for all servos for the current gait and phase).
        -1 <= `turn_dir` <= 1 gives the turn strength and direction.
        `rev` == True inverses the sequence.
        If `stop` is True, `turn_dir` is ignored.
    """
    def _set_leg(legs, a_cox, a_fem, d_coxL=1, d_coxR=1):
      for iL in legs:
        if iL % 2 == 0:
          # Even leg index -> left side leg
          pol = d_coxL
        else:
          # Odd leg index -> right side leg
          pol = d_coxR
        out[cfg.SRV_COX[iL]] = int(a_cox) *cfg.SRV_COX_DIR[iL] *pol
        out[cfg.SRV_FEM[iL]] = int(a_fem)

    # Get parameters and go to next phase
    seq = self._seq
    asw = self._aCoxaSwing_deg if seq == super().NORMAL else -self._aCoxaSwing_deg
    ac0 = self._aCoxaCenter_deg
    alf = self._aLgLift_deg
    apl = self._aLgPreLift_deg
    adn = self._aLgDown_deg
    rat = self._phaseRatio
    dtp = self._tPhase_ms
    trj = sma.TRJ_SINE
    lift_from_neutral = False
    dt_ms = dtp

    out = array.array("h", [0]*cfg.SRV_COUNT)

    if stop:
      # Stopped, move to neutral position
      _set_leg(self._legSets[0], ac0, adn)
      _set_leg(self._legSets[1], ac0, adn)
      self._isInSeq = False
      self._phase = 0

    else:
      if not self._isInSeq:
        # Not yet running, move to neutral position
        self._isInSeq = True
        lift_from_neutral = True

      # Move ...
      tlc = 1
      trc = 1
      if abs(turn_dir) > 0.001:
        tlc = -1 if turn_dir > 0 else 1
        trc = -1 if turn_dir < 0 else 1

      # Leg servo angles according to phase
      phs = self._phase
      if self._subtype == 0:
        # Move leg sets up/down at the same time (4 phases)
        #
        if phs == 0:   # Lift 1st set of legs and set down other set
          asw = 0 if lift_from_neutral else asw
          _set_leg(self._legSets[0],  asw, alf, tlc, trc)  # legs 0,3,4
          _set_leg(self._legSets[1], -asw, adn, tlc, trc)  # legs 1,2,5
          dt_ms *= rat if not rev else (1-rat)

        elif phs == 1: # Move lifted set legs
          _set_leg(self._legSets[0], -asw, alf, tlc, trc)
          _set_leg(self._legSets[1],  asw, adn, tlc, trc)
          dt_ms *= (1 -rat) if not rev else rat

        elif phs == 2: # Set down 1st set of legs and lift other set up
          _set_leg(self._legSets[0], -asw, adn, tlc, trc)
          _set_leg(self._legSets[1],  asw, alf, tlc, trc)
          dt_ms *= rat if not rev else (1-rat)

        elif phs == 3: # Move lifted set legs
          _set_leg(self._legSets[0],  asw, adn, tlc, trc)
          _set_leg(self._legSets[1], -asw, alf, tlc, trc)
          dt_ms *= (1 -rat) if not rev else rat

      elif self._subtype == 1:
        # Move leg sets seperately up and down (6 phases)
        #
        if phs == 0:   # Just lift 1st set of legs
          asw = 0 if lift_from_neutral else asw
          _set_leg(self._legSets[0],  asw, apl, tlc, trc)  # legs 0,3,4
          _set_leg(self._legSets[1], -asw, adn, tlc, trc)  # legs 1,2,5
          dt_ms *= rat if not rev else (1-rat)
          #trj = sma.TRJ_RAMP_UP

        elif phs == 1: # Move lifted set legs
          _set_leg(self._legSets[0], -asw, alf, tlc, trc)
          _set_leg(self._legSets[1],  asw, adn, tlc, trc)
          dt_ms *= (1 -rat) if not rev else rat

        elif phs == 2: # Set down 1st set of legs
          _set_leg(self._legSets[0], -asw, adn, tlc, trc)
          _set_leg(self._legSets[1],  asw, adn, tlc, trc)
          dt_ms *= rat if not rev else (1-rat)
          #trj = sma.TRJ_RAMP_DOWN

        elif phs == 3: # Now just lift 2nd set of legs
          _set_leg(self._legSets[0], -asw, adn, tlc, trc)
          _set_leg(self._legSets[1],  asw, apl, tlc, trc)
          dt_ms *= rat if not rev else (1-rat)
          #trj = sma.TRJ_RAMP_UP

        elif phs == 4: # Move lifted set legs
          _set_leg(self._legSets[0],  asw, adn, tlc, trc)
          _set_leg(self._legSets[1], -asw, alf, tlc, trc)
          dt_ms *= (1 -rat) if not rev else rat

        elif phs == 5: # Set down 1st set of legs
          _set_leg(self._legSets[0],  asw, adn, tlc, trc)
          _set_leg(self._legSets[1], -asw, adn, tlc, trc)
          dt_ms *= rat if not rev else (1-rat)
          #trj = sma.TRJ_RAMP_DOWN

      if not rev:
        self._phase = phs +1 if phs < self._nPhase-1 else 0
      else:
        self._phase = phs -1 if phs > 0 else self._nPhase-1

    # Return time to move and angle array
    return int(dt_ms), out, trj

# ----------------------------------------------------------------------------

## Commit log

2022-04-18 STLs uploaded
    [leg_coxa_femur_v1.stl, leg_link_bottom_v1.stl, leg_link_top_v1.stl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]
2022-04-18 Some first code for testing a leg
2022-06-04 Update body frame
    [body_frame_v1.stl, body_v1.stl]
2022-06-05 More code
    [body_frame_v1.stl, leg.scad, main_v4.scad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]
2022-07-10 Parts updated
    [converter_holder_v1.stl, main_v5.scad]
2022-08-08 3D files updated
    [leg.scad, leg_tibia_tarsus_v2.stl, leg_tibia_tarsus_v2_adapter_v1.stl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]
